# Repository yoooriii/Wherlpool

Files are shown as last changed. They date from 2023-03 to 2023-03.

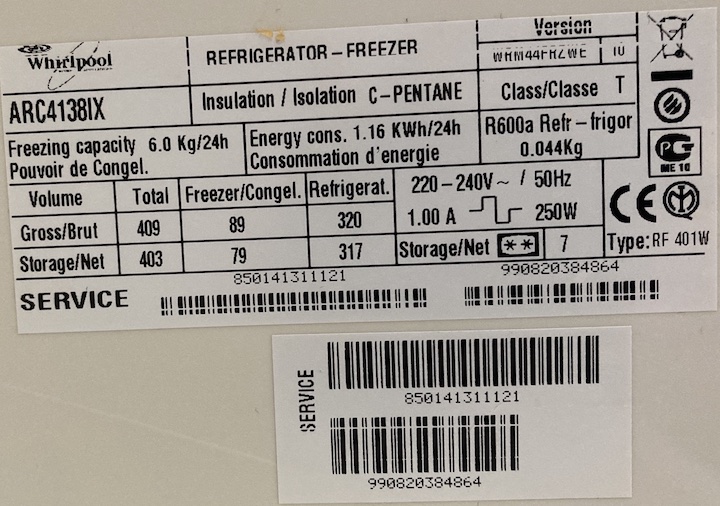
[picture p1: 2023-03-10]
pictures/specs.jpeg

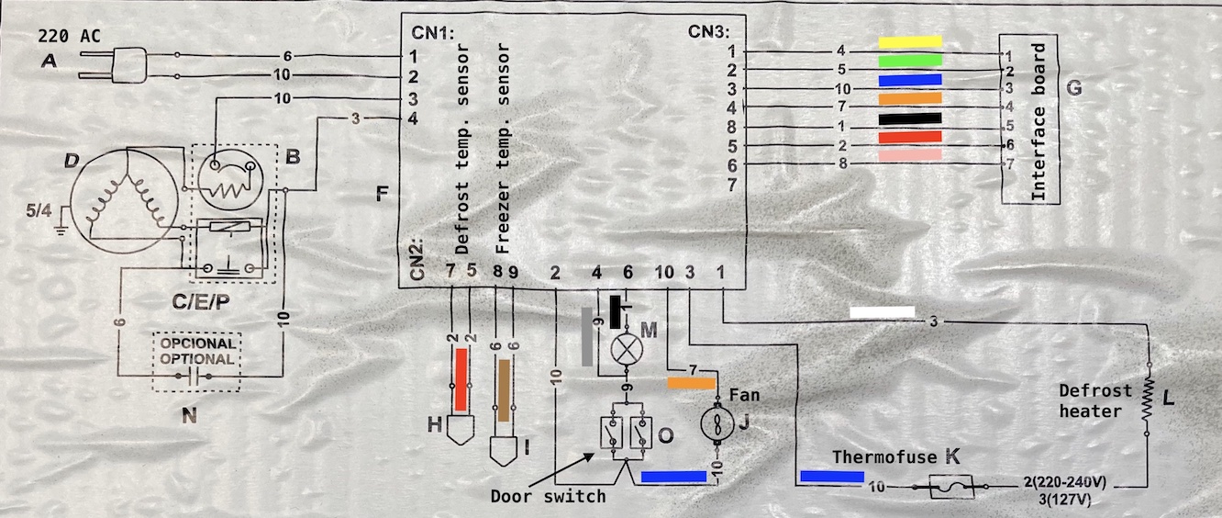
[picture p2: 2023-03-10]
pictures/schematic2.jpeg

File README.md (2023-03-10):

# Wherlpool
Whirlpool refrigerator Arduino ATmega8 circuit board and code project.

It features DS1302 timekeeping chip.
Arduino Library: Copyright (c) 2009, Matt Sparks (2-clause BSD license).
[DS1302 RTC library for Arduino](https://github.com/msparks/arduino-ds1302)

About this project:
It contains all documents to assemble and program a circuit board for
a Whirlpool refrigerator, or any other refrigerator with a few (or none) modifications.
It consists of 2 projects:
+ Eagle CAD circuit board
+ Arduino based firmware (ATmega8)

### PCB signal connections:

```
[Signal name]           : [pin] : [direction]
CP = control panel      : ----------
CP Reset button         : PD3   : in
CP +/- (up/dn) button   : PD4   : in
CP Led1                 : PC3   : out
CP Led2                 : PC4   : out
CP Led3                 : PC5   : out
MB = main board         : ----------
Defrost sensor          : ADC6  : in
Freezer sensor          : ADC7  : in
Door open sw            : PD2   : in
Fan 12V                 : PB1   : out
Motor                   : PB0   : out
Defrost heater          : PD5   : out
```

Other things:

In the freezer compartment I am using 2x 12V fans taken from used ATX power supply units.
One blows in the freezer and another blows from the freezer to the main compartment (+5C).
They work quite well, the only thing to consider is, as soon as fans work at low temperature 
I had to use full synthetic low temperature oil (Nissan 5w30 motor oil in my case). Before that they worked well
up to -5 -10 Celsius, but at -20 ... -30 Celsius they became too noisy and I had to oil them.

TODO:
defrost timer.
It is not implemented yet.
Logic: once each 1-2 days the fridge must be defrozen.
1. turn the compressor off and 
2. turn the heater on for 15-20 (30) minutes.
Additionally: save the last successful heating time. Note: electricity may go off so I should keep settings in DS1302 RAM.
(For some reason ATmega8 eerprom gets corrupted in my case, looks like sporadic code executed when power goes down)

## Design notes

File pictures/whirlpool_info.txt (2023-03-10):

Thermo sensor "I Freezer temp sensor" - brown-brown
Temp 	: Resistance
+25.0	: 2.4k
 -0.5	: 8.8k
-20.0	: 25k
-30.0	: 40k

10 pin socket:
MF-10MRA (N42GP-10) Ninigi
step 4.2 mm, 2х5

Defrost heater: R=210 ohm, at 220v it makes 230 W.

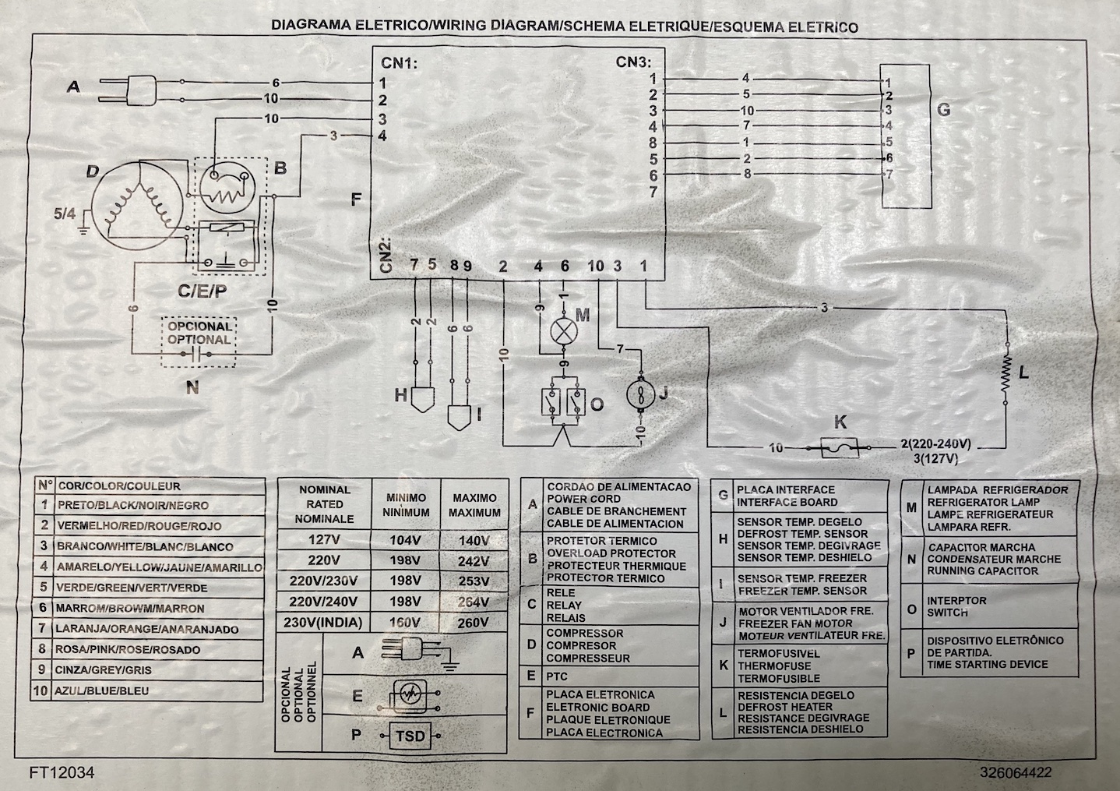
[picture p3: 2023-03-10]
pictures/schematic.jpeg

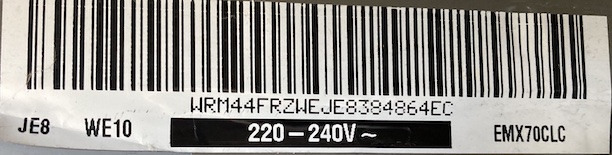
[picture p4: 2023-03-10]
pictures/barcode.jpeg

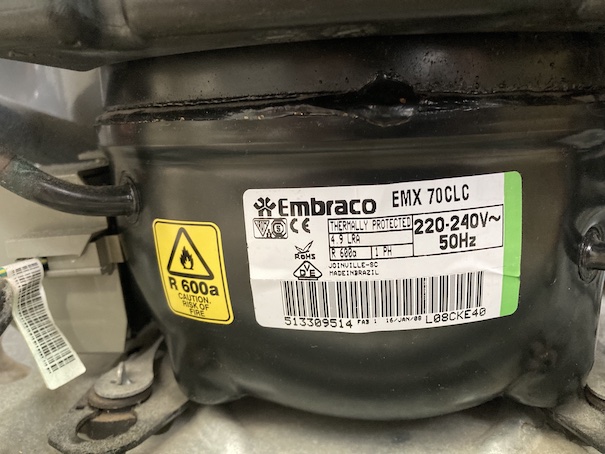
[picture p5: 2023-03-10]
pictures/motor.jpeg

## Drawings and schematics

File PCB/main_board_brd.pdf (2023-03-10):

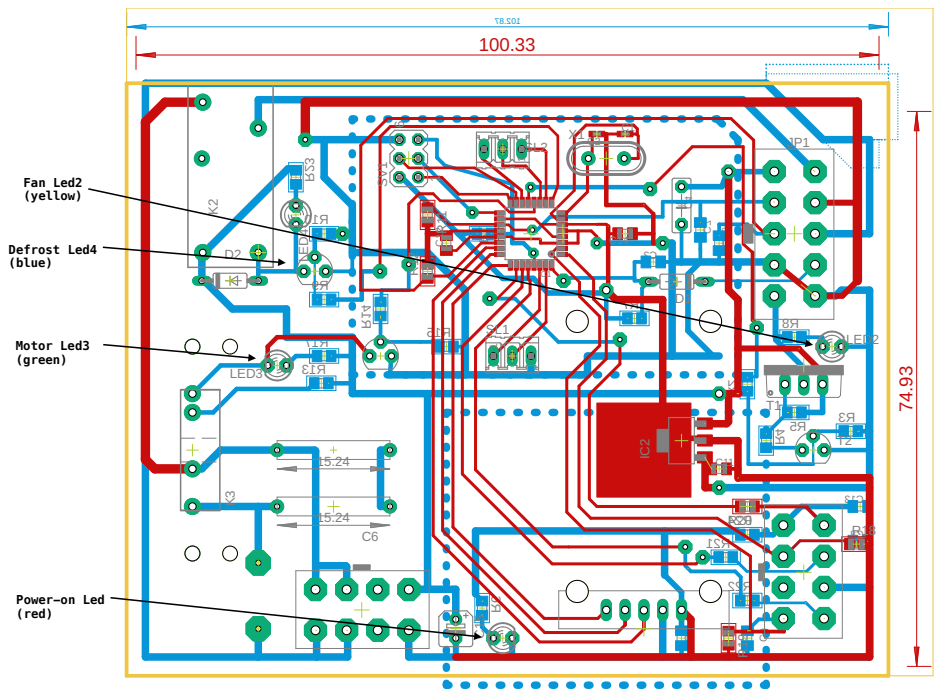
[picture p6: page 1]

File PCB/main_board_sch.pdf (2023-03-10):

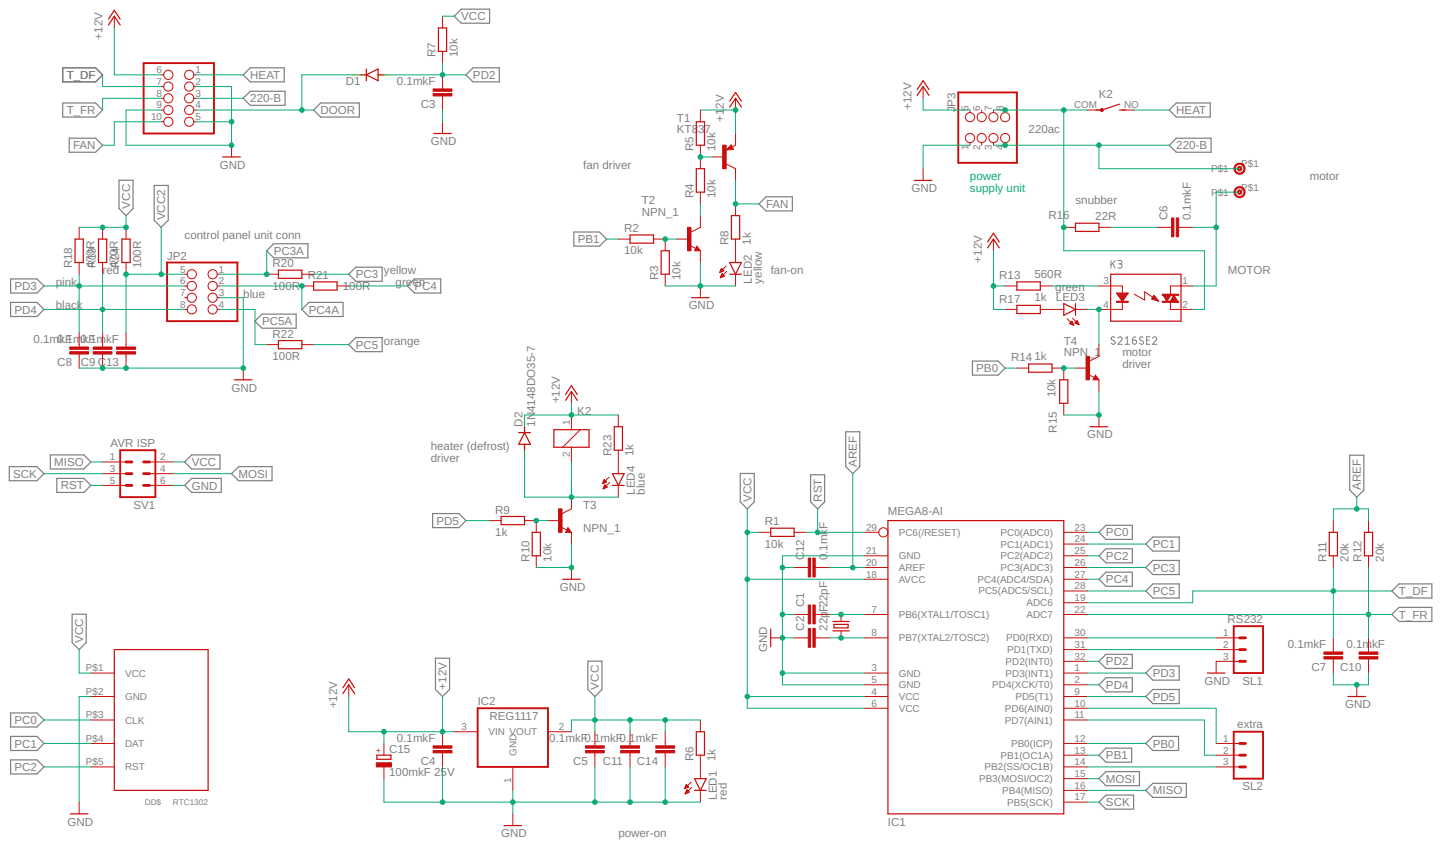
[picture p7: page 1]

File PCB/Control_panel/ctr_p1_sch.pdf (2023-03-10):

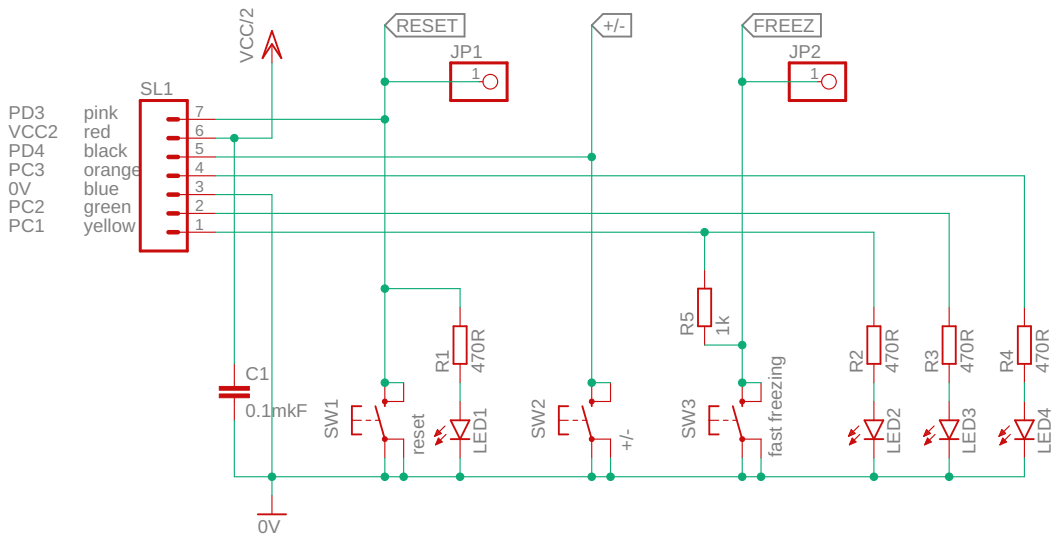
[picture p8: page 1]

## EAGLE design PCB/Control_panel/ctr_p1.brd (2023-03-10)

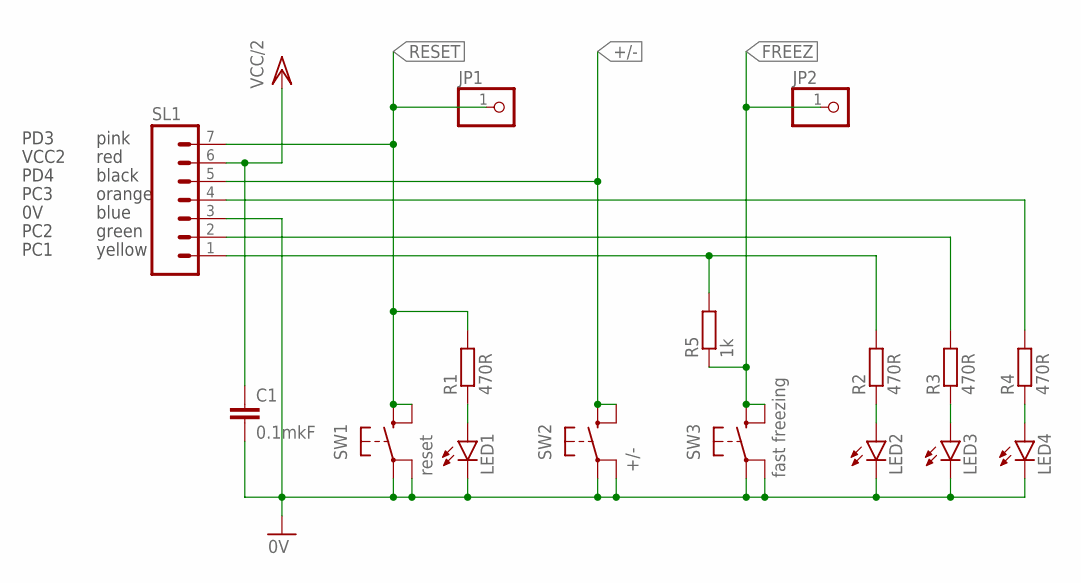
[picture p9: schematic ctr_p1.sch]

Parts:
C1: 0.1mkF; C3225
JP1, JP2: PINHD-1X1; 1X01
LED1, LED2, LED3, LED4: LED3MM
R1, R2, R3, R4: 470R; R0805
R5: 1k; R0805
SL1: MA07; 07PA
SW1: reset; SWITCH
SW2: +/-; SWITCH
SW3: fast freezing; SWITCH

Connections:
0V: C1.2, LED1.K (C), LED2.K (C), LED3.K (C), LED4.K (C), SL1.3, SW1.P$1A, SW1.P$2A (P1), SW2.P$1A, SW2.P$2A (P1), SW3.P$1A, SW3.P$2A (P1)
+/-: SL1.5, SW2.P$1B (S), SW2.P$2B (S1)
FREEZ: JP2.1, R5.1, SW3.P$1B (S), SW3.P$2B (S1)
unnamed: LED2.A, R2.1
unnamed: LED3.A, R3.1
unnamed: LED4.A, R4.1
unnamed: R2.2, R5.2, SL1.1
unnamed: R3.2, SL1.2
unnamed: R4.2, SL1.4
unnamed: LED1.A, R1.1
RESET: JP1.1, R1.2, SL1.7, SW1.P$1B (S), SW1.P$2B (S1)
VCC/2: C1.1, SL1.6

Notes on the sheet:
yellow
green
blue
orange
black
red
pink
PD3
PD4
PC1
PC2
PC3
VCC2

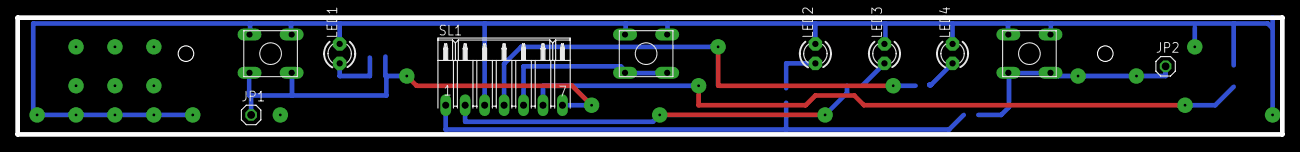
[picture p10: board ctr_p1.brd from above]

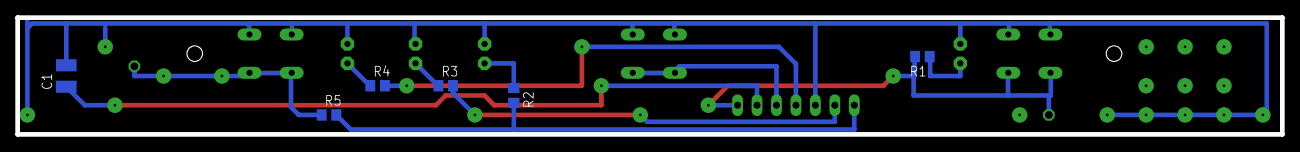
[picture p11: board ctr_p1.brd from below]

Board: 2 copper layers, 165.1 x 15.2 mm, 16 parts (6 on the bottom side), 12 nets.

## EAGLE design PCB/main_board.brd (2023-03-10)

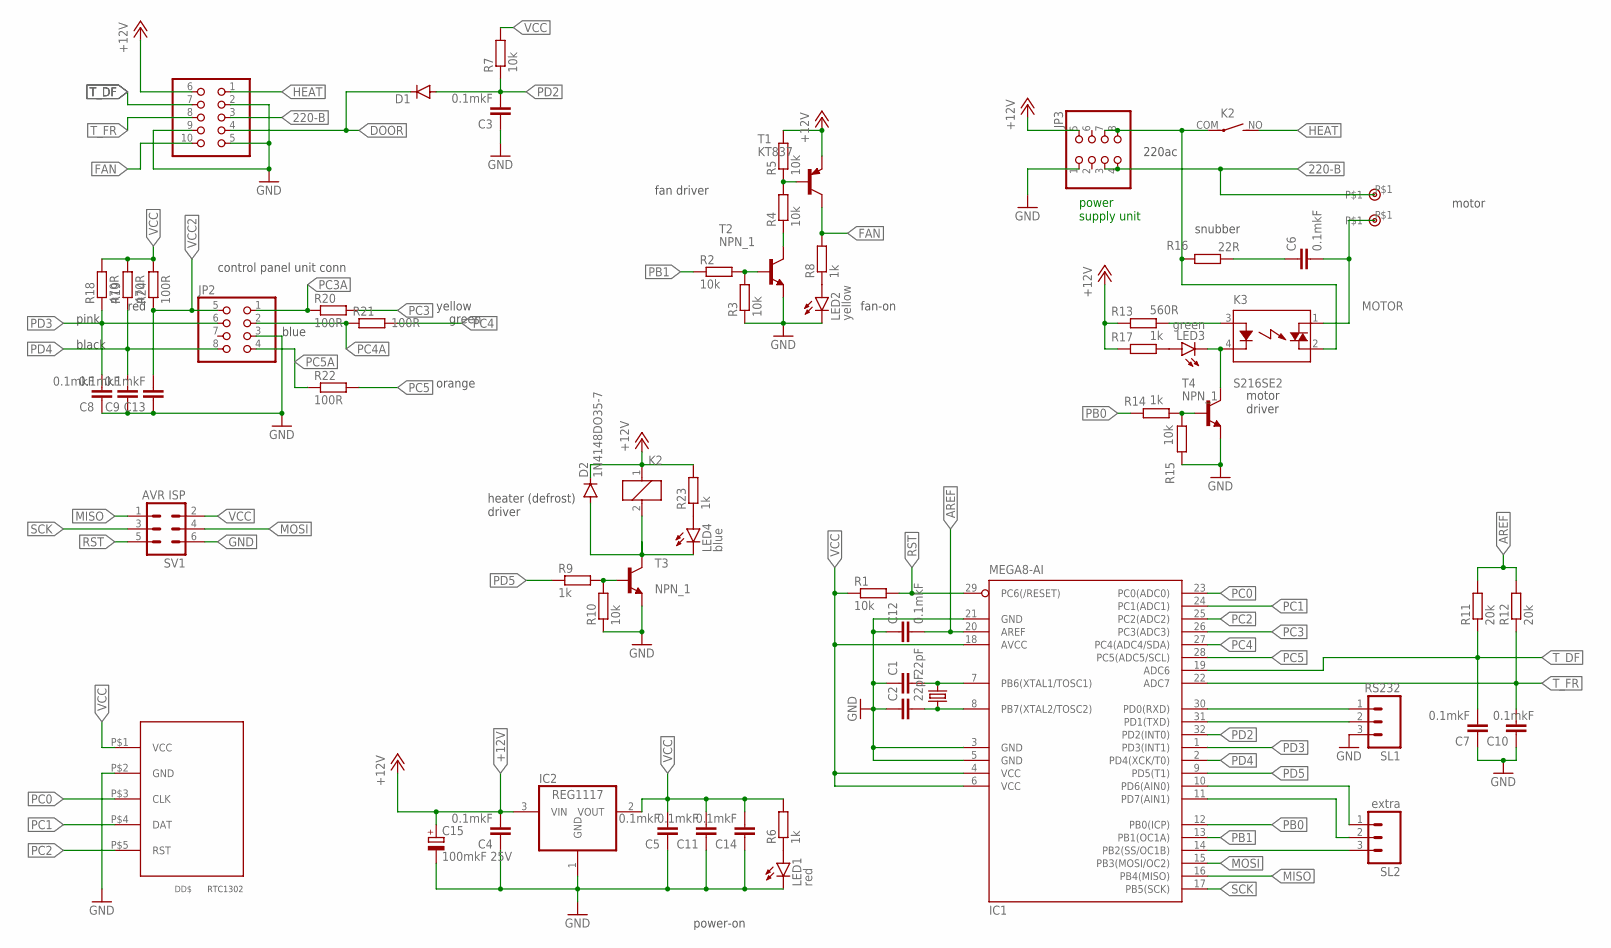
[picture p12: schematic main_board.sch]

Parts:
C1, C2: 22pF; C0402K
C3, C5, C7, C8, C9, C10, C11, C12, C13, C14: 0.1mkF; C0805K
C4: 0.1mkF; C5B2.5
C6: 0.1mkF; PACK_2PIN_150
C15: 100mkF 25V; B45181A
CN1, CN2: CONTACT
D1, D2: 1N4148DO35-7; DO35-7
DD1: RTC-DS1302-MODULEABOVE; RTC-DS1302-M2
IC1: MEGA8-AI; TQFP32-08
IC2: REG1117; SOT223
JP1: CONN_2X5_4.2MMANGLE-0; CONN_2X05_4.2MM
JP2, JP3: CONN_2X4_4.2MM; CONN_2X04_4.2MM
K2: RELAY_ALK3213; ALK3213
K3: S216SE2; S2XXEX
LED1: red; LED3MM
LED2: yellow; LED3MM
LED3: green; LED3MM
LED4: blue; LED3MM
R1, R2, R3, R4, R5, R7, R10, R15: 10k; R0805
R6, R8, R9, R14, R17, R23: 1k; R0805
R11, R12: 20k; R0805
R13: 560R; R0805
R16: 22R; PACK_2PIN_150
R18, R19: 470R; R0805
R20, R21, R22, R24: 100R; R0805
SL1: RS232; 03P
SL2: extra; 03P
SV1: AVR ISP; MA03-2
T1: KT837; TO220V
T2, T3, T4: NPN_1; TO92
X1: 16MHz; HC49

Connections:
220-A: JP3.7, JP3.8, K2.COM, K3.2 (DS2), R16.P$2 (2)
220-B: CN1.P$1, JP1.3, JP3.3, JP3.4
+12V: C4.2, C15.+, D2.C, IC2.3 (VIN), JP1.6, JP3.5, K2.1, R5.2, R13.1, R17.1, R23.2, T1.3 (E)
AREF: C12.2, IC1.20 (AREF), R11.2, R12.2
DOOR: D1.C, JP1.4
FAN: JP1.10, R8.2, T1.2 (C)
GND: C1.1, C2.1, C3.1, C4.1, C5.1, C7.1, C8.1, C9.1, C10.1, C11.1, C12.1, C13.1, C14.1, C15.-, DD1.P$2 (GND), IC1.3 (GND), IC1.5 (GND), IC1.21 (GND), IC2.1 (GND), JP1.2, JP1.5, JP1.9, JP2.3, JP3.1, LED1.K (C), LED2.K (C), R3.1, R10.1, R15.1, SL1.3, SV1.6, T2.E, T3.E, T4.E
HEAT: JP1.1, K2.NO (S)
MISO: IC1.16 (PB4(MISO)), SV1.1
MOSI: IC1.15 (PB3(MOSI/OC2)), SV1.4
MOTOR: C6.P$2 (2), CN2.P$1, K3.1 (DS1)
unnamed: C6.P$1 (1), R16.P$1 (1)
unnamed: R9.2, R10.2, T3.B
unnamed: R2.2, R3.2, T2.B
unnamed: R4.1, T2.C
unnamed: R4.2, R5.1, T1.1 (B)
unnamed: LED1.A, R6.1
unnamed: IC1.30 (PD0(RXD)), SL1.1
unnamed: LED2.A, R8.1
unnamed: IC1.31 (PD1(TXD)), SL1.2
unnamed: K3.3 (A), R13.2
unnamed: R14.2, R15.2, T4.B
unnamed: K3.4 (K), LED3.K (C), T4.C
unnamed: LED3.A, R17.2
unnamed: IC1.10 (PD6(AIN0)), SL2.1
unnamed: IC1.11 (PD7(AIN1)), SL2.2
unnamed: IC1.14 (PB2(SS/OC1B)), SL2.3
unnamed: LED4.A, R23.1
unnamed: D2.A, K2.2, LED4.K (C), T3.C
PB0: IC1.12 (PB0(ICP)), R14.1
PB1: IC1.13 (PB1(OC1A)), R2.1
PC0: DD1.P$3 (CLK), IC1.23 (PC0(ADC0))
PC1: DD1.P$4 (DAT), IC1.24 (PC1(ADC1))
PC2: DD1.P$5 (RST), IC1.25 (PC2(ADC2))
PC3: IC1.26 (PC3(ADC3)), R20.2
PC3A: JP2.1, R20.1
PC4: IC1.27 (PC4(ADC4/SDA)), R21.2
PC4A: JP2.2, R21.1
PC5: IC1.28 (PC5(ADC5/SCL)), R22.2
PC5A: JP2.4, R22.1
PD2: C3.2, D1.A, IC1.32 (PD2(INT0)), R7.1
PD3: C8.2, IC1.1 (PD3(INT1)), JP2.6, R18.1
PD4: C9.2, IC1.2 (PD4(XCK/T0)), JP2.8, R19.1
PD5: IC1.9 (PD5(T1)), R9.1
RST: IC1.29 (PC6(/RESET)), R1.2, SV1.5
SCK: IC1.17 (PB5(SCK)), SV1.3
T_DF: C7.2, IC1.19 (ADC6), JP1.7, R11.1
T_FR: C10.2, IC1.22 (ADC7), JP1.8, R12.1
VCC: C5.2, C11.2, C14.2, DD1.P$1 (VCC), IC1.4 (VCC), IC1.6 (VCC), IC1.18 (AVCC), IC2.2 (VOUT), R1.1, R6.2, R7.2, R18.2, R19.2, R24.2, SV1.2
VCC2: C13.2, JP2.5, R24.1
XTAL1: C1.2, IC1.7 (PB6(XTAL1/TOSC1)), X1.2
XTAL2: C2.2, IC1.8 (PB7(XTAL2/TOSC2)), X1.1

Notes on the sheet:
power-on
fan-on
heater (defrost) driver
220ac
motor
motor driver
snubber
blue
orange
yellow
green
red
pink
black
control panel unit conn
fan driver
power supply unit

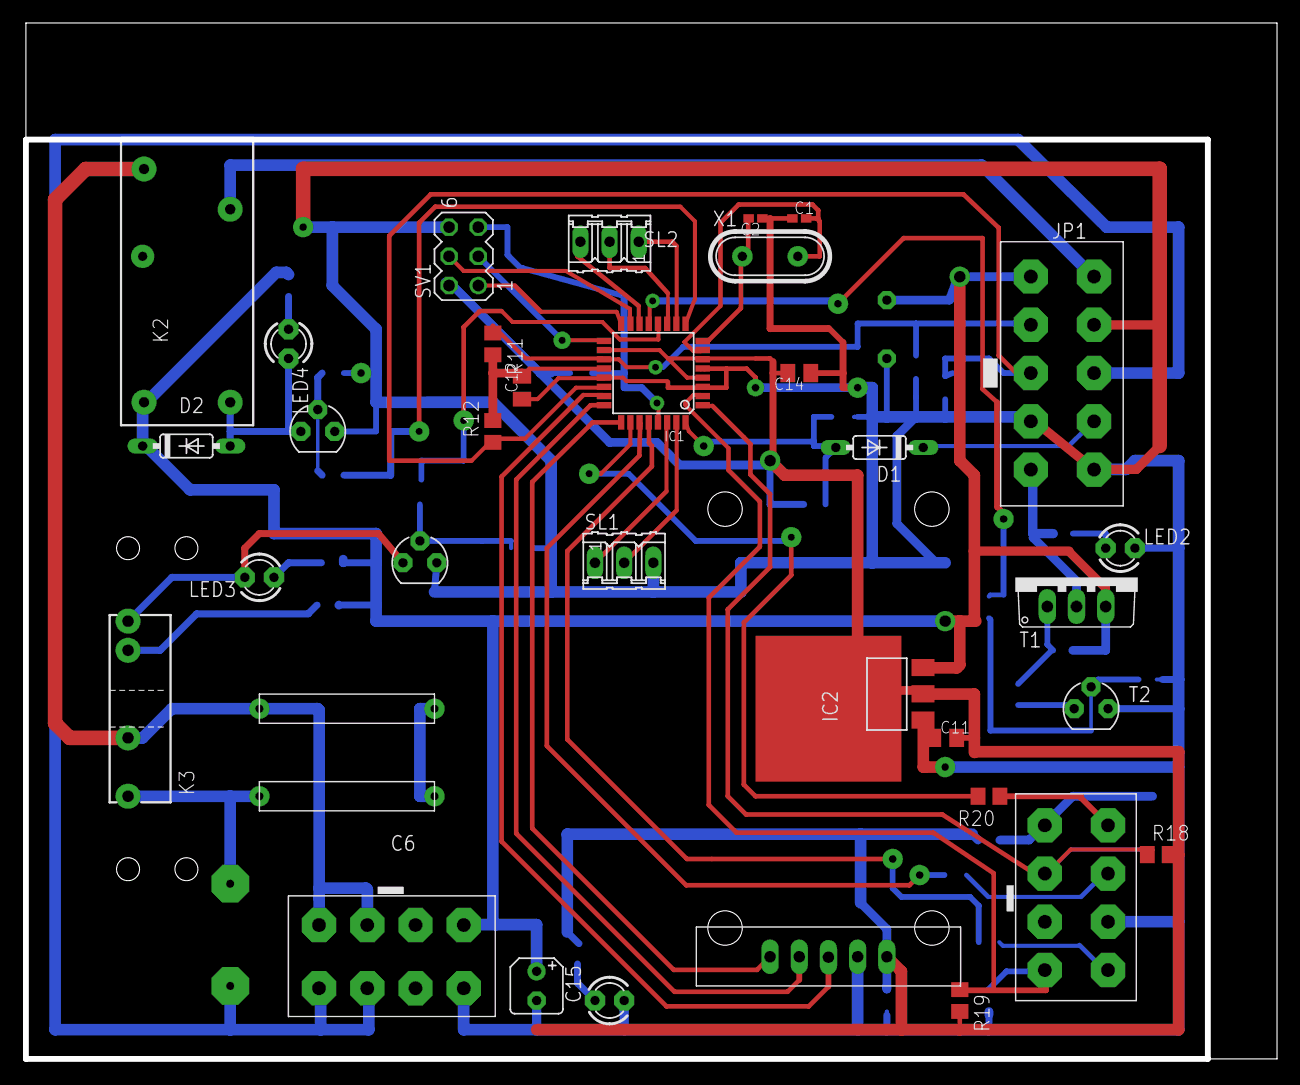
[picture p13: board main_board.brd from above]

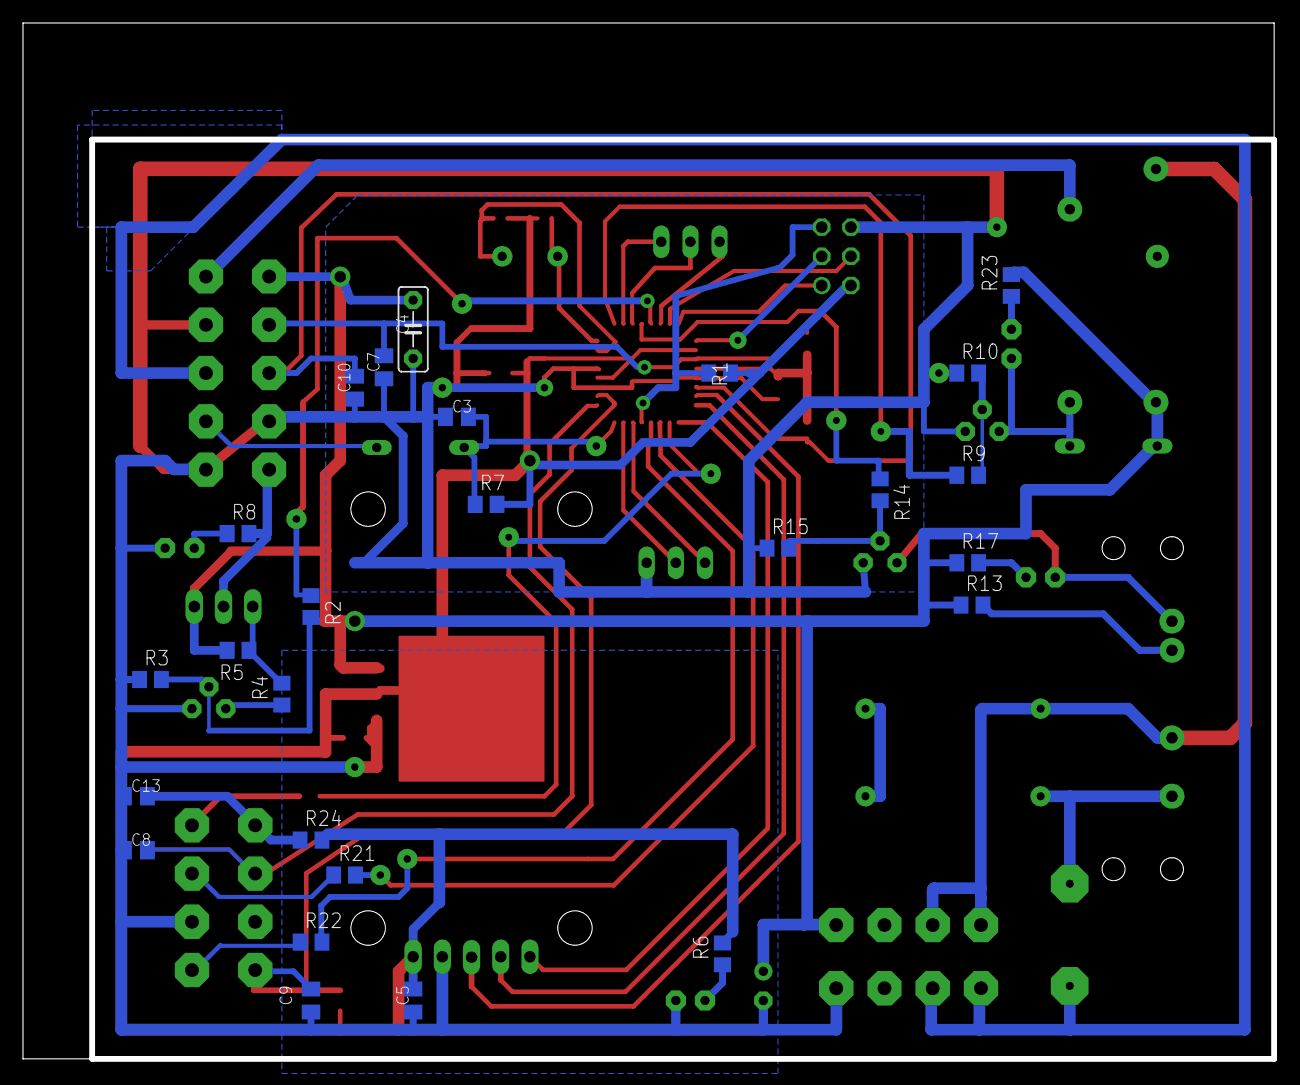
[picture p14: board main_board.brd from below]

Board: 2 copper layers, 108.9 x 90.2 mm, 63 parts (26 on the bottom side), 52 nets.

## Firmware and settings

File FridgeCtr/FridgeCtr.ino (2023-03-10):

/*

*/

#include <EEPROM.h>
#include <DS1302.h>
#include "FridgeSupport.h"


void printMetrics();
void loopMotorControl();


// Set the appropriate digital I/O pin connections. These are the pin
// assignments for the Arduino as well for as the DS1302 chip. See the DS1302
// datasheet:
//
//   http://datasheets.maximintegrated.com/en/ds/DS1302.pdf
const int kCePin   = PIN_PC2;  // Chip Enable
const int kIoPin   = PIN_PC1;  // Input/Output
const int kSclkPin = PIN_PC0;  // Serial Clock

// Create a DS1302 object.
DS1302 rtc(kCePin, kIoPin, kSclkPin);

void printTime() {
  // Get the current time and date from the chip.
  TimeD2 t;
  rtc.readTime(&t);

  // Format the time and date and insert into the temporary buffer.
  char buf[50];
  snprintf(buf, sizeof(buf), "%04d-%02d-%02d %02d:%02d:%02d",
           t.yr, t.mon, t.date,
           t.hr, t.min, t.sec);

  // Print the formatted string to serial so we can see the time.
  Serial.println(buf);
}


void setTemperatureMode(uint8_t tempMode);
void readTemperatureMode();

uint8_t lastButtonState = HIGH;  // the previous reading from the input pin
unsigned long lastDebounceTime = 0;  // the last time the output pin was toggled
unsigned long debounceDelay = 50;    // the debounce time; increase if the output flickers
uint8_t temperatureMode = 0;

const int getTemperatureOff() {
  switch (temperatureMode)
  {
  case 0:
    return 400; // -9-10C
  case 1:
    return 460; // -13C
  case 2:
    return 530; // -17C
  case 3:
    return 575; // -20C
  default:
    return 1024; // max
  }
}

void switchTemperature() {
  ++temperatureMode;
  if (temperatureMode > 3) {
    temperatureMode = 1;
  }
  setTemperatureMode(temperatureMode);
}

const uint8_t TempModeAddr = 0; 

void setTemperatureMode(uint8_t tempMode) {
  rtc.writeRam(TempModeAddr, tempMode);
  turnTempLed(tempMode);
}

void readTemperatureMode() {
  const uint8_t tempMode = rtc.readRam(TempModeAddr);
  Serial.print("Temp mode read:");
  Serial.println(tempMode);

  if (tempMode > 5) {
    temperatureMode = 0;
    rtc.writeRam(TempModeAddr, 0);
  } else {
    temperatureMode = tempMode;
  }
  turnTempLed(temperatureMode);
}

void readButtons() {
  // read the state of the switch into a local variable:
  const uint8_t reading = digitalRead(pp_UpDn);
  if (reading == lastButtonState) {
    const unsigned long dt = (0L == lastDebounceTime) ? 0L : millis() - lastDebounceTime;
    if (dt > debounceDelay) {
      lastDebounceTime = 0; // stop debouncing timer
      if (reading == HIGH) {
        // button released, switch temperature      
        switchTemperature();
      }
    }

    return;
  }
  
  // the button state has changed --> restart the debouncing timer
  lastDebounceTime = millis();
  lastButtonState = reading;
}

void setupRTC() {
    // Initialize a new chip by turning off write protection and clearing the
  // clock halt flag. These methods needn't always be called. See the DS1302
  // datasheet for details.
  rtc.writeProtect(false);
  rtc.halt(false);

  TimeD2 t;
  rtc.readTime(&t);
  if (t.yr < 5) {
    t.yr = 6;
    t.mon = 1;
    t.date = 1;
    t.hr = 0;
    t.min = 0;
    t.sec = 0;
    // Set the time and date on the chip.
    rtc.writeTime(&t);
  }
}

// the setup function runs once when you press reset or power the board
void setup() {
  pinMode(pp_Fan, OUTPUT);
  pinMode(pp_Motor, OUTPUT);
  pinMode(pp_Heater, OUTPUT);
  pinMode(pp_Led1, OUTPUT);
  pinMode(pp_Led2, OUTPUT);
  pinMode(pp_Led3, OUTPUT);

  pinMode(pp_TDF, INPUT);
  pinMode(pp_Thermo, INPUT);
  pinMode(pp_Door, INPUT);
  pinMode(pp_Reset, INPUT);
  pinMode(pp_UpDn, INPUT);

  measureReset();

  // initialize serial communication at 9600 bits per second:
  Serial.begin(9600);
  setupRTC();
  readTemperatureMode();

  Serial.println("setup-end");
  // dumpTemp();
}

uint8_t skipLoop = 0;

// the loop function runs over and over again forever
void loop() {
  readButtons();

  const uint8_t door_open = isDoorOpen();
  // const uint8_t isReset = isResetButtonOn();

  turnFan(!door_open);

  /// if not heating then motor control
  loopMotorControl();


  ++skipLoop;
  if (skipLoop > 20) {
    skipLoop = 0;
    // dumpTemp();
    printMetrics();
  }
  
  delay(100);
}

void loopMotorControl() {
  measureTemp();
  const int avgTemp = getAvgTemp();
  const int tempOff = getTemperatureOff();
  if (0) {
    Serial.print("MCtr, avg:");
    Serial.print(avgTemp);
    Serial.print("; toff:");
    Serial.print(tempOff);
    Serial.print(";");
  }

  if (isMotorOn()) {
    // motor is running, check if the temperature is higher than requested
    if (avgTemp > tempOff) {
      turnMotor(LOW);
    }
  } else {
    // motor is not running, check if the temperature is back minus histeresis
    if (avgTemp < (tempOff - 20)) {
      turnMotor(HIGH);
    }
  }
}

void printMetrics() {
  Serial.print("Temp.mode:");
  Serial.print(temperatureMode);
  Serial.print("; Temp.off:");
  Serial.print(getTemperatureOff());
  Serial.println(";");

  // read the temp sensor value
  int sensorValue1 = getAvgTemp();
  Serial.print("Temp.avg.Fr:");
  Serial.print(sensorValue1);
  Serial.print(";  ");
  
// read the defrost sensor value
  int sensorValue2 = getTempDf();
  Serial.print("Temp.Df:");
  Serial.print(sensorValue2);
  Serial.print(";  ");

  Serial.print("Motor:");
  Serial.print(isMotorOn());
  Serial.println(";");

  printTime();
}

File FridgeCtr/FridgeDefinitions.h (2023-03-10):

// FridgeDefinitions.h
// Wherlpool

#include <pins_arduino.h>

#ifndef _FRIDGE_DEFINITIONS_
#define _FRIDGE_DEFINITIONS_

#define pp_Fan (PIN_PB1)
#define pp_Motor (PIN_PB0)
#define pp_Heater (PIN_PD5)

// defrost sensor, analog input
#define pp_TDF (PIN_A6)
// thermo sensor, analog input
#define pp_Thermo (PIN_A7)
#define pp_Door (PIN_PD2)

// reset button
#define pp_Reset (PIN_PD3)
// +/- (up/down) button
#define pp_UpDn (PIN_PD4)
// 3 temperature mode leds
#define pp_Led1 (PIN_PC3)
#define pp_Led2 (PIN_PC4)
#define pp_Led3 (PIN_PC5)

// heat time in minutes
#define HeatTime (15)

#endif

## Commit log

2023-03-10 add Eagle PCB project
    [ctr_p1.brd, ctr_p1.sch, main_board.brd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]
2023-03-10 add Arduino firmware project
